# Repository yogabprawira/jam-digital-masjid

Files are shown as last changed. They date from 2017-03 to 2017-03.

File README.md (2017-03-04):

# Jam Digital Masjid

Bahan-bahan yang digunakan:
- Arduino Pro Mini 5V
- Modul RTC DS3231 (sepaket dengan EEPROM AT24C32) 
- MP1584 Buck / Step Down 3A Adjustable Regulator Module
- PCB
- Seven segment
- Resistor
- Kabel
- Power supply (adaptor dengan jack DC 12V) 

Seven segment yang digunakan:
- 4 buah seven segment untuk tampilan jam
- 6 buah seven segment untuk tampilan tanggal/hari
- 4 buah seven segment untuk tampilan jadwal x 6 (Imsyak, Shubuh, Zuhur, Asar, Maghrib, Isya)

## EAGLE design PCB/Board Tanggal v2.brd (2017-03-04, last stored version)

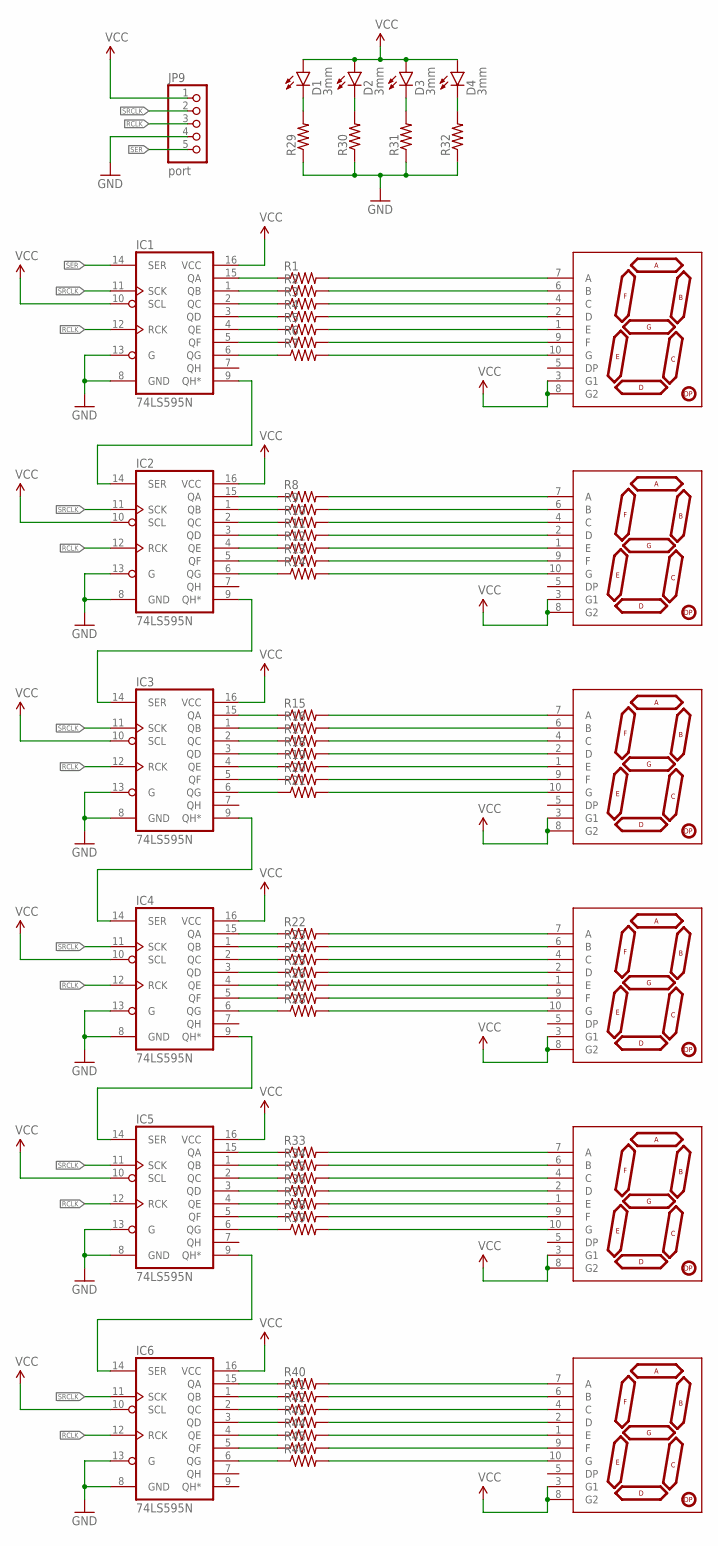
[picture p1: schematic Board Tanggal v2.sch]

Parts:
D1, D2, D3, D4: 3mm; LED3MM
IC1, IC2, IC3, IC4, IC5, IC6: 74LS595N; DIL16
JP9: port; 1X05
R1, R2, R3, R4, R5, R6, R7, R8, R9, R10, R11, R12, R13, R14, R15, R16, R17, R18, R19, R20, R21, R22, R23, R24, R25, R26, R27, R28, R29, R30, R31, R32, R33, R34, R35, R36, R37, R38, R39, R40, R41, R42, R43, R44, R45, R46: RESISTORPTH-1/4W; AXIAL-0.4
U$1, U$2, U$3, U$4, U$5, U$6: 7-SEGMENT-DISPLAY-1"-REDEZ; 7-SEGMENT-1"PTH-EZ

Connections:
A_0: R1.P$2 (2), U$1.7 (A)
A_2: R15.P$2 (2), U$3.7 (A)
A_3: R22.P$2 (2), U$4.7 (A)
A_4: R33.P$2 (2), U$5.7 (A)
A_5: R40.P$2 (2), U$6.7 (A)
B_0: R2.P$2 (2), U$1.6 (B)
B_1: R9.P$2 (2), U$2.6 (B)
B_2: R16.P$2 (2), U$3.6 (B)
B_3: R23.P$2 (2), U$4.6 (B)
B_4: R34.P$2 (2), U$5.6 (B)
B_5: R41.P$2 (2), U$6.6 (B)
C_0: R3.P$2 (2), U$1.4 (C)
C_1: R10.P$2 (2), U$2.4 (C)
C_2: R17.P$2 (2), U$3.4 (C)
C_3: R24.P$2 (2), U$4.4 (C)
C_4: R35.P$2 (2), U$5.4 (C)
C_5: R42.P$2 (2), U$6.4 (C)
D_0: R4.P$2 (2), U$1.2 (D)
D_1: R11.P$2 (2), U$2.2 (D)
D_2: R18.P$2 (2), U$3.2 (D)
D_3: R25.P$2 (2), U$4.2 (D)
D_4: R36.P$2 (2), U$5.2 (D)
D_5: R43.P$2 (2), U$6.2 (D)
E_0: R5.P$2 (2), U$1.1 (E)
E_1: R12.P$2 (2), U$2.1 (E)
E_2: R19.P$2 (2), U$3.1 (E)
E_3: R26.P$2 (2), U$4.1 (E)
E_4: R37.P$2 (2), U$5.1 (E)
E_5: R44.P$2 (2), U$6.1 (E)
F_0: R6.P$2 (2), U$1.9 (F)
F_1: R13.P$2 (2), U$2.9 (F)
F_2: R20.P$2 (2), U$3.9 (F)
F_3: R27.P$2 (2), U$4.9 (F)
F_4: R38.P$2 (2), U$5.9 (F)
F_5: R45.P$2 (2), U$6.9 (F)
GND: IC1.8 (GND), IC1.13 (G), IC2.8 (GND), IC2.13 (G), IC3.8 (GND), IC3.13 (G), IC4.8 (GND), IC4.13 (G), IC5.8 (GND), IC5.13 (G), IC6.8 (GND), IC6.13 (G), JP9.4, R29.P$1 (1), R30.P$1 (1), R31.P$1 (1), R32.P$1 (1)
G_0: R7.P$2 (2), U$1.10 (G)
G_1: R14.P$2 (2), U$2.10 (G)
G_2: R21.P$2 (2), U$3.10 (G)
G_3: R28.P$2 (2), U$4.10 (G)
G_4: R39.P$2 (2), U$5.10 (G)
G_5: R46.P$2 (2), U$6.10 (G)
unnamed: IC1.15 (QA), R1.P$1 (1)
unnamed: IC2.15 (QA), R8.P$1 (1)
unnamed: IC1.1 (QB), R2.P$1 (1)
unnamed: IC1.2 (QC), R3.P$1 (1)
unnamed: IC1.3 (QD), R4.P$1 (1)
unnamed: IC1.4 (QE), R5.P$1 (1)
unnamed: IC1.5 (QF), R6.P$1 (1)
unnamed: IC1.6 (QG), R7.P$1 (1)
unnamed: IC2.1 (QB), R9.P$1 (1)
unnamed: IC2.2 (QC), R10.P$1 (1)
unnamed: IC2.3 (QD), R11.P$1 (1)
unnamed: IC2.4 (QE), R12.P$1 (1)
unnamed: IC2.5 (QF), R13.P$1 (1)
unnamed: IC2.6 (QG), R14.P$1 (1)
unnamed: IC3.15 (QA), R15.P$1 (1)
unnamed: IC3.1 (QB), R16.P$1 (1)
unnamed: IC3.2 (QC), R17.P$1 (1)
unnamed: IC3.3 (QD), R18.P$1 (1)
unnamed: IC3.4 (QE), R19.P$1 (1)
unnamed: IC3.5 (QF), R20.P$1 (1)
unnamed: IC3.6 (QG), R21.P$1 (1)
unnamed: IC4.15 (QA), R22.P$1 (1)
unnamed: IC4.1 (QB), R23.P$1 (1)
unnamed: IC4.2 (QC), R24.P$1 (1)
unnamed: IC4.3 (QD), R25.P$1 (1)
unnamed: IC4.4 (QE), R26.P$1 (1)
unnamed: IC4.5 (QF), R27.P$1 (1)
unnamed: IC4.6 (QG), R28.P$1 (1)
unnamed: IC1.9 (QH*), IC2.14 (SER)
unnamed: IC2.9 (QH*), IC3.14 (SER)
unnamed: IC3.9 (QH*), IC4.14 (SER)
unnamed: D1.K (C), R29.P$2 (2)
unnamed: D2.K (C), R30.P$2 (2)
unnamed: D3.K (C), R31.P$2 (2)
unnamed: D4.K (C), R32.P$2 (2)
unnamed: IC5.15 (QA), R33.P$1 (1)
unnamed: IC5.1 (QB), R34.P$1 (1)
unnamed: IC5.2 (QC), R35.P$1 (1)
unnamed: IC5.3 (QD), R36.P$1 (1)
unnamed: IC5.4 (QE), R37.P$1 (1)
unnamed: IC5.5 (QF), R38.P$1 (1)
unnamed: IC5.6 (QG), R39.P$1 (1)
unnamed: IC4.9 (QH*), IC5.14 (SER)
unnamed: IC6.15 (QA), R40.P$1 (1)
unnamed: IC6.1 (QB), R41.P$1 (1)
unnamed: IC6.2 (QC), R42.P$1 (1)
unnamed: IC6.3 (QD), R43.P$1 (1)
unnamed: IC6.4 (QE), R44.P$1 (1)
unnamed: IC6.5 (QF), R45.P$1 (1)
unnamed: IC6.6 (QG), R46.P$1 (1)
unnamed: IC5.9 (QH*), IC6.14 (SER)
unnamed: R8.P$2 (2), U$2.7 (A)
RCLK: IC1.12 (RCK), IC2.12 (RCK), IC3.12 (RCK), IC4.12 (RCK), IC5.12 (RCK), IC6.12 (RCK), JP9.3
SER: IC1.14 (SER), JP9.5
SRCLK: IC1.11 (SCK), IC2.11 (SCK), IC3.11 (SCK), IC4.11 (SCK), IC5.11 (SCK), IC6.11 (SCK), JP9.2
VCC: D1.A, D2.A, D3.A, D4.A, IC1.10 (SCL), IC1.16 (VCC), IC2.10 (SCL), IC2.16 (VCC), IC3.10 (SCL), IC3.16 (VCC), IC4.10 (SCL), IC4.16 (VCC), IC5.10 (SCL), IC5.16 (VCC), IC6.10 (SCL), IC6.16 (VCC), JP9.1, U$1.3 (G1), U$1.8 (G2), U$2.3 (G1), U$2.8 (G2), U$3.3 (G1), U$3.8 (G2), U$4.3 (G1), U$4.8 (G2), U$5.3 (G1), U$5.8 (G2), U$6.3 (G1), U$6.8 (G2)

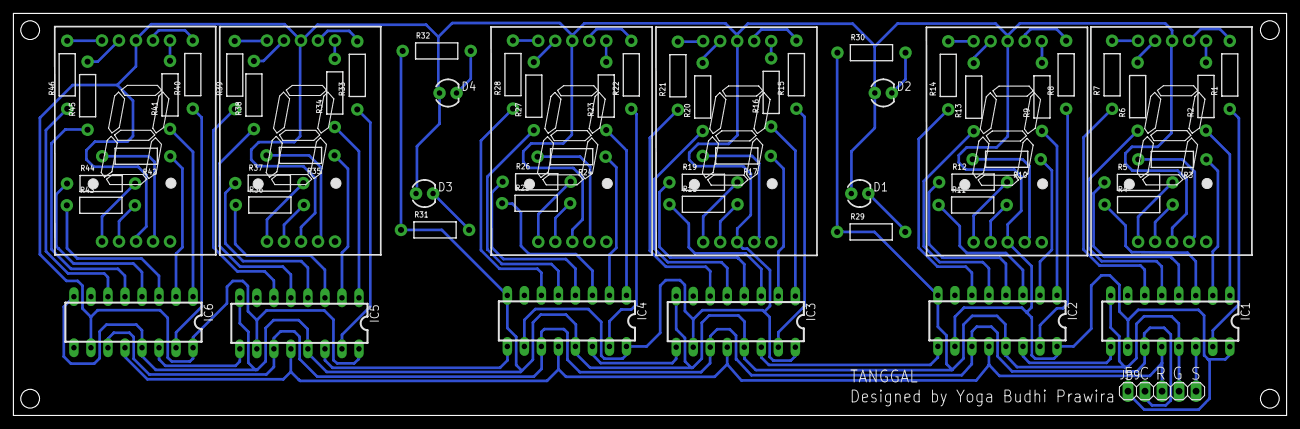
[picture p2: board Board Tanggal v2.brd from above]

Board: 2 copper layers, 190.0 x 60.0 mm, 63 parts (0 on the bottom side), 98 nets.

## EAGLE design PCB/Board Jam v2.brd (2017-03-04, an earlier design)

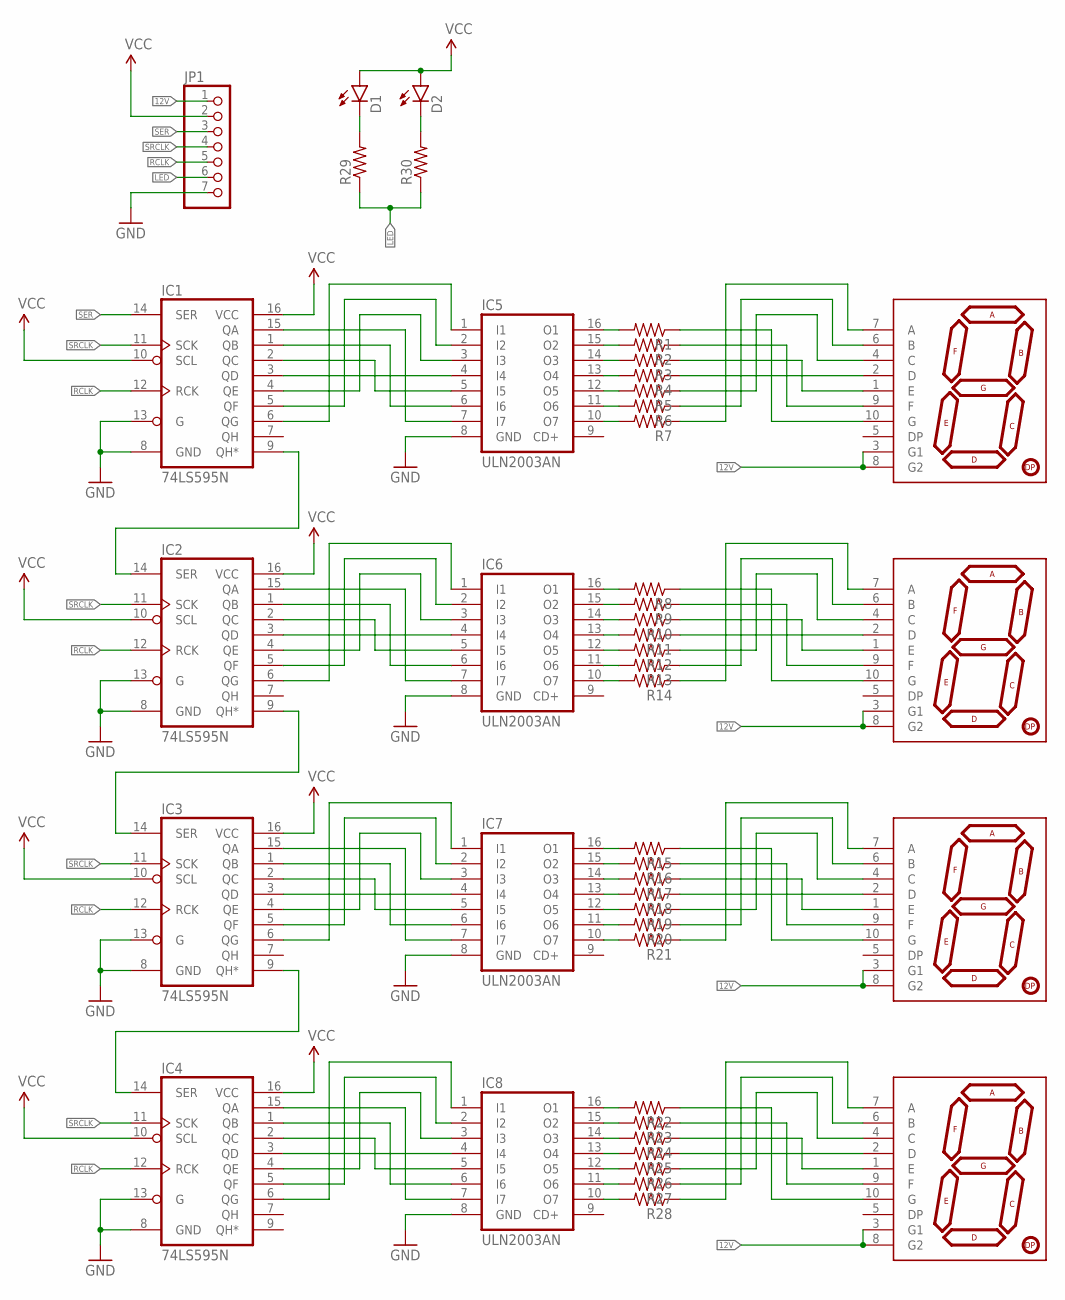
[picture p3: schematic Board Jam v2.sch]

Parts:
D1, D2: LED5MM
IC1, IC2, IC3, IC4: 74LS595N; DIL16
IC5, IC6, IC7, IC8: ULN2003AN; DIL16
JP1: PINHD-1X7; 1X07
R1, R2, R3, R4, R5, R6, R7, R8, R9, R10, R11, R12, R13, R14, R15, R16, R17, R18, R19, R20, R21, R22, R23, R24, R25, R26, R27, R28, R29, R30: RESISTORPTH-1/4W; AXIAL-0.4
U$1, U$2, U$3, U$4: 7-SEGMENT-DISPLAY-1"-RED7-SEGMENT-1.8"PTH; 7-SEGMENT-1"PTH

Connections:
12V: JP1.1, U$1.3 (G1), U$1.8 (G2), U$2.3 (G1), U$2.8 (G2), U$3.3 (G1), U$3.8 (G2), U$4.3 (G1), U$4.8 (G2)
GND: IC1.8 (GND), IC1.13 (G), IC2.8 (GND), IC2.13 (G), IC3.8 (GND), IC3.13 (G), IC4.8 (GND), IC4.13 (G), IC5.8 (GND), IC6.8 (GND), IC7.8 (GND), IC8.8 (GND), JP1.7
LED: JP1.6, R29.P$1 (1), R30.P$1 (1)
unnamed: IC1.15 (QA), IC5.7 (I7)
unnamed: IC2.15 (QA), IC6.7 (I7)
unnamed: IC1.1 (QB), IC5.6 (I6)
unnamed: IC1.2 (QC), IC5.5 (I5)
unnamed: IC1.3 (QD), IC5.4 (I4)
unnamed: IC1.4 (QE), IC5.3 (I3)
unnamed: IC1.5 (QF), IC5.2 (I2)
unnamed: IC1.6 (QG), IC5.1 (I1)
unnamed: IC2.1 (QB), IC6.6 (I6)
unnamed: IC2.2 (QC), IC6.5 (I5)
unnamed: IC2.3 (QD), IC6.4 (I4)
unnamed: IC2.4 (QE), IC6.3 (I3)
unnamed: IC2.5 (QF), IC6.2 (I2)
unnamed: IC2.6 (QG), IC6.1 (I1)
unnamed: IC6.16 (O1), R8.P$2 (2)
unnamed: IC6.15 (O2), R9.P$2 (2)
unnamed: IC6.14 (O3), R10.P$2 (2)
unnamed: IC6.13 (O4), R11.P$2 (2)
unnamed: IC6.12 (O5), R12.P$2 (2)
unnamed: IC6.11 (O6), R13.P$2 (2)
unnamed: IC6.10 (O7), R14.P$2 (2)
unnamed: IC3.15 (QA), IC7.7 (I7)
unnamed: IC3.1 (QB), IC7.6 (I6)
unnamed: IC3.2 (QC), IC7.5 (I5)
unnamed: IC3.3 (QD), IC7.4 (I4)
unnamed: IC3.4 (QE), IC7.3 (I3)
unnamed: IC3.5 (QF), IC7.2 (I2)
unnamed: IC3.6 (QG), IC7.1 (I1)
unnamed: IC1.9 (QH*), IC2.14 (SER)
unnamed: IC2.9 (QH*), IC3.14 (SER)
unnamed: IC3.9 (QH*), IC4.14 (SER)
unnamed: D1.K (C), R29.P$2 (2)
unnamed: D2.K (C), R30.P$2 (2)
unnamed: IC7.16 (O1), R15.P$2 (2)
unnamed: IC5.16 (O1), R1.P$2 (2)
unnamed: IC5.15 (O2), R2.P$2 (2)
unnamed: IC5.14 (O3), R3.P$2 (2)
unnamed: IC5.13 (O4), R4.P$2 (2)
unnamed: IC5.12 (O5), R5.P$2 (2)
unnamed: IC5.11 (O6), R6.P$2 (2)
unnamed: IC5.10 (O7), R7.P$2 (2)
unnamed: IC7.15 (O2), R16.P$2 (2)
unnamed: IC7.14 (O3), R17.P$2 (2)
unnamed: IC7.13 (O4), R18.P$2 (2)
unnamed: IC7.12 (O5), R19.P$2 (2)
unnamed: IC7.11 (O6), R20.P$2 (2)
unnamed: IC7.10 (O7), R21.P$2 (2)
unnamed: IC4.15 (QA), IC8.7 (I7)
unnamed: IC4.1 (QB), IC8.6 (I6)
unnamed: IC4.2 (QC), IC8.5 (I5)
unnamed: IC4.3 (QD), IC8.4 (I4)
unnamed: IC4.4 (QE), IC8.3 (I3)
unnamed: IC4.5 (QF), IC8.2 (I2)
unnamed: IC4.6 (QG), IC8.1 (I1)
unnamed: IC8.16 (O1), R22.P$2 (2)
unnamed: IC8.15 (O2), R23.P$2 (2)
unnamed: IC8.14 (O3), R24.P$2 (2)
unnamed: IC8.13 (O4), R25.P$2 (2)
unnamed: IC8.12 (O5), R26.P$2 (2)
unnamed: IC8.11 (O6), R27.P$2 (2)
unnamed: IC8.10 (O7), R28.P$2 (2)
unnamed: R1.P$1 (1), U$1.10 (G)
unnamed: R2.P$1 (1), U$1.9 (F)
unnamed: R3.P$1 (1), U$1.1 (E)
unnamed: R4.P$1 (1), U$1.2 (D)
unnamed: R5.P$1 (1), U$1.4 (C)
unnamed: R6.P$1 (1), U$1.6 (B)
unnamed: R7.P$1 (1), U$1.7 (A)
unnamed: R8.P$1 (1), U$2.10 (G)
unnamed: R9.P$1 (1), U$2.9 (F)
unnamed: R10.P$1 (1), U$2.1 (E)
unnamed: R11.P$1 (1), U$2.2 (D)
unnamed: R12.P$1 (1), U$2.4 (C)
unnamed: R13.P$1 (1), U$2.6 (B)
unnamed: R14.P$1 (1), U$2.7 (A)
unnamed: R15.P$1 (1), U$3.10 (G)
unnamed: R16.P$1 (1), U$3.9 (F)
unnamed: R17.P$1 (1), U$3.1 (E)
unnamed: R18.P$1 (1), U$3.2 (D)
unnamed: R19.P$1 (1), U$3.4 (C)
unnamed: R20.P$1 (1), U$3.6 (B)
unnamed: R21.P$1 (1), U$3.7 (A)
unnamed: R22.P$1 (1), U$4.10 (G)
unnamed: R23.P$1 (1), U$4.9 (F)
unnamed: R24.P$1 (1), U$4.1 (E)
unnamed: R25.P$1 (1), U$4.2 (D)
unnamed: R26.P$1 (1), U$4.4 (C)
unnamed: R27.P$1 (1), U$4.6 (B)
unnamed: R28.P$1 (1), U$4.7 (A)
RCLK: IC1.12 (RCK), IC2.12 (RCK), IC3.12 (RCK), IC4.12 (RCK), JP1.5
SER: IC1.14 (SER), JP1.3
SRCLK: IC1.11 (SCK), IC2.11 (SCK), IC3.11 (SCK), IC4.11 (SCK), JP1.4
VCC: D1.A, D2.A, IC1.10 (SCL), IC1.16 (VCC), IC2.10 (SCL), IC2.16 (VCC), IC3.10 (SCL), IC3.16 (VCC), IC4.10 (SCL), IC4.16 (VCC), JP1.2

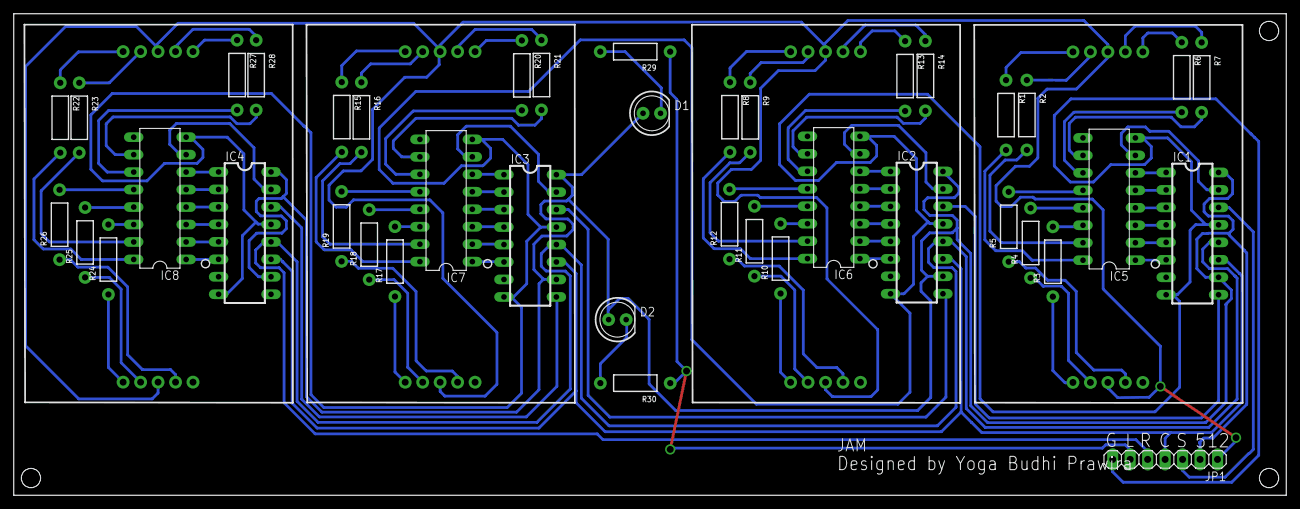
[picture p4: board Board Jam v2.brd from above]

Board: 2 copper layers, 185.0 x 70.0 mm, 45 parts (0 on the bottom side), 96 nets.

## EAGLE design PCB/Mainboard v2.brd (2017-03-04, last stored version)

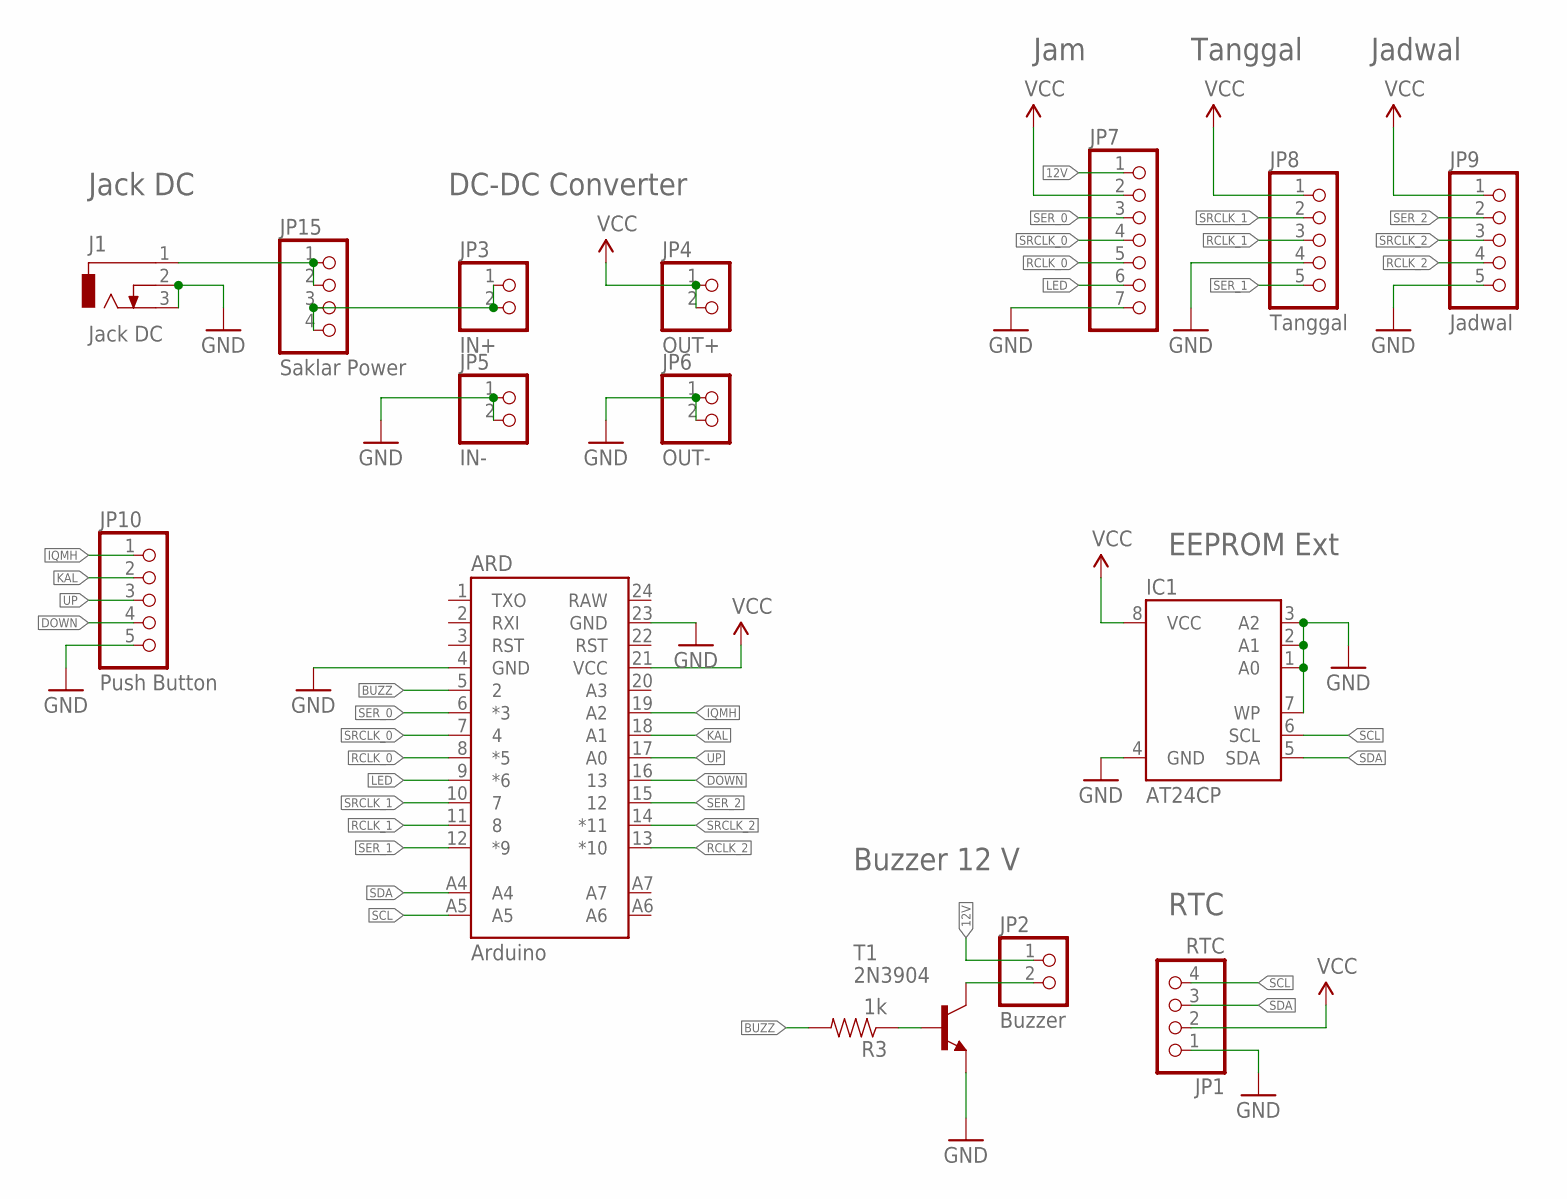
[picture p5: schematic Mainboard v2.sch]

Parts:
ARD: Arduino; ARDUINO_PRO_MINI
IC1: AT24CP; DIL08
J1: Jack DC; DCJ0202
JP1: RTC; 1X04
JP2: Buzzer; 1X02
JP3: IN+; 1X02
JP4: OUT+; 1X02
JP5: IN-; 1X02
JP6: OUT-; 1X02
JP7: PINHD-1X7; 1X07
JP8: Tanggal; 1X05
JP9: Jadwal; 1X05
JP10: Push Button; 1X05
JP15: Saklar Power; 1X04
R3: 1k; AXIAL-0.4
T1: 2N3904; TO92

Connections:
12V: JP2.1, JP3.1, JP3.2, JP7.1, JP15.3, JP15.4
BUZZ: ARD.5 (2), R3.P$2 (2)
DOWN: ARD.16 (13), JP10.4
GND: ARD.4 (GND), ARD.23 (GND), IC1.1 (A0), IC1.2 (A1), IC1.3 (A2), IC1.4 (GND), IC1.7 (WP), J1.2, J1.3, JP1.1, JP5.1, JP5.2, JP6.1, JP6.2, JP7.7, JP8.4, JP9.5, JP10.5, T1.3 (E)
IQMH: ARD.19 (A2), JP10.1
KAL: ARD.18 (A1), JP10.2
LED: ARD.9 (*6), JP7.6
unnamed: R3.P$1 (1), T1.2 (B)
unnamed: J1.1, JP15.1, JP15.2
unnamed: JP2.2, T1.1 (C)
RCLK_0: ARD.8 (*5), JP7.5
RCLK_1: ARD.11 (8), JP8.3
RCLK_2: ARD.13 (*10), JP9.4
SCL: ARD.A5, IC1.6 (SCL), JP1.4
SDA: ARD.A4, IC1.5 (SDA), JP1.3
SER_0: ARD.6 (*3), JP7.3
SER_1: ARD.12 (*9), JP8.5
SER_2: ARD.15 (12), JP9.2
SRCLK_0: ARD.7 (4), JP7.4
SRCLK_1: ARD.10 (7), JP8.2
SRCLK_2: ARD.14 (*11), JP9.3
UP: ARD.17 (A0), JP10.3
VCC: ARD.21 (VCC), IC1.8 (VCC), JP1.2, JP4.1, JP4.2, JP7.2, JP8.1, JP9.1

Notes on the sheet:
RTC
EEPROM Ext
Buzzer 12 V
DC-DC Converter
Jam
Tanggal
Jadwal
Jack DC

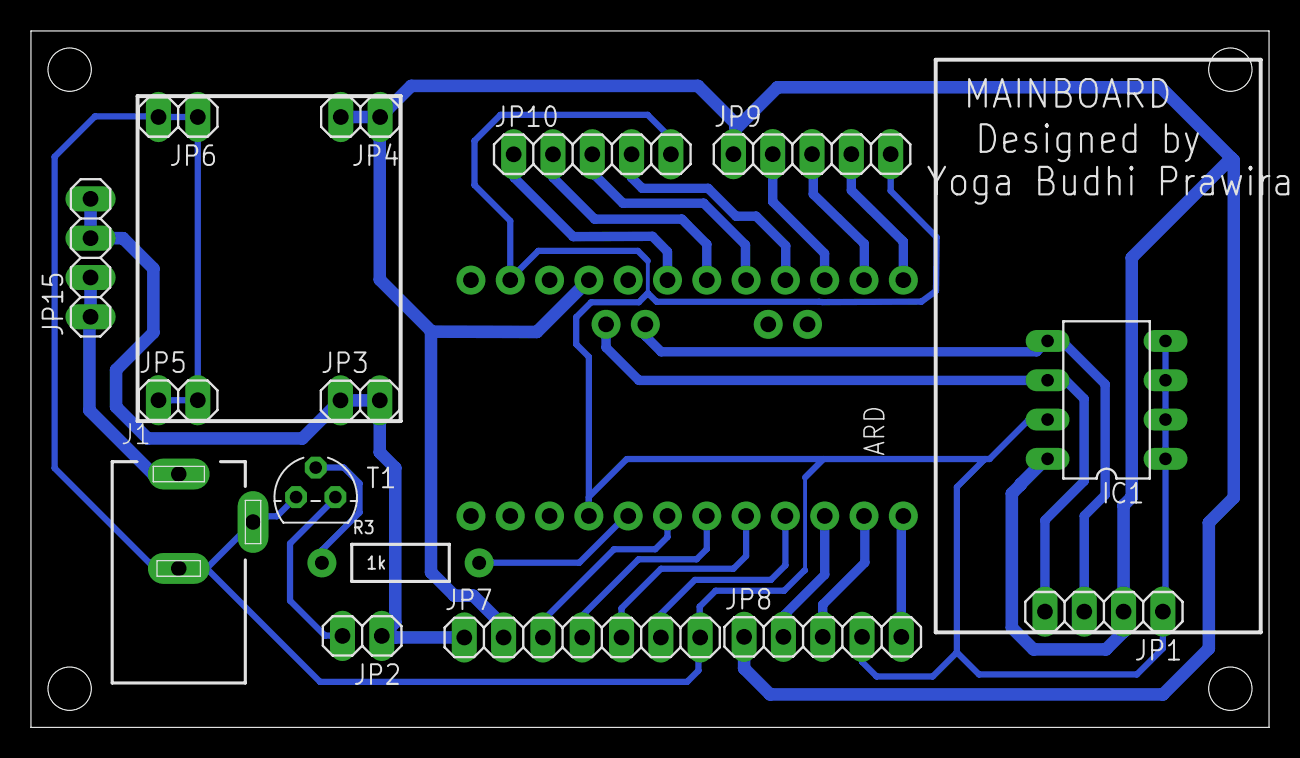
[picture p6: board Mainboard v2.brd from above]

Board: 2 copper layers, 80.0 x 45.0 mm, 16 parts (0 on the bottom side), 23 nets.

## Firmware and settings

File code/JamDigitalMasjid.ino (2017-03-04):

/*
 Name 			:	JamDigitalMasjid.ino
 Created		:	1/26/2016 9:41:18 PM
 Author			:	Yoga Budhi Prawira
 Description	:	Program jam digital masjid sederhana menggunakan arduino pro mini
*/

#include <Wire.h>
#include "AT24C64.h"
#include "Iqomah.h"
#include "Tombol.h"
#include "Kedip.h"
#include "DataJadwalSholat.h"
#include "SevenSegment.h"
#include "JamDigital.h"

/* (SER, RCLK, SRCLK) */
SevenSegment boardJam(3, 5, 4);
SevenSegment boardTanggal(9, 8, 7);
SevenSegment boardJadwal(12, 10, 11);

Kedip buzzer(2);
Kedip ledJam(6);
//Tombol tombolKal(A1);
Tombol tombolIq(A2);
//Tombol tombolGerak(A0);
//Tombol tombolOk(13);

static uint8_t detik, menit, jam, hari, tanggal, bulan, tahun;
static uint8_t menitIqomah, detikIqomah;
//static uint8_t menitKalib, detikKalib;
//static boolean stateInKal = HIGH;
//static boolean stateOutKal = LOW;
//static boolean stateOutKalPrev;
static boolean stateInIq = HIGH;
static boolean stateOutIq = LOW;
static boolean stateOutIqPrev;
//static boolean stateInGer = HIGH;
//static boolean stateOutGer = LOW;
//static boolean stateOutGerPrev = LOW;
//static boolean stateInOk = HIGH;
//static boolean stateOutOk = LOW;
static boolean buzzerNyala;

void setup() {
	//Serial.begin(9600);

	/* Kalibrasi waktu RTC : detik, menit, jam, hari, tanggal, bulan, tahun */
	//jamDigital.kalibrasiRealTime(__DATE__, __TIME__);

	/* Menulis data jadwal sholat ke EEPROM Ext */
	//int i, j;
	/*int bulanTest = DESEMBER;
	for (i = 0; i < 31; i++) {
		for (j = 0; j < 6; j++) {
			dataEepromJadwalSholat.tulisByte(ALAMAT_EEPROM_DS3231, ((bulanTest-1)*186)+(i*6)+j, jadwalSholat.desember[i][j]);
			delay(10);
		}
	}*/
	/* Read EEPROM Test */
	/*for (i = 1; i <= 31; i++) {
		Serial.print(jadwalSholat.jamImsyak(i, bulanTest));
		Serial.print(":");
		Serial.print(jadwalSholat.menitImsyak(i, bulanTest));
		Serial.print(" ");
		Serial.print(jadwalSholat.jamSubuh(i, bulanTest));
		Serial.print(":");
		Serial.print(jadwalSholat.menitSubuh(i, bulanTest));
		Serial.print(" ");
		Serial.print(jadwalSholat.jamDzuhur(i, bulanTest));
		Serial.print(":");
		Serial.print(jadwalSholat.menitDzuhur(i, bulanTest));
		Serial.print(" ");
		Serial.print(jadwalSholat.jamAsar(i, bulanTest));
		Serial.print(":");
		Serial.print(jadwalSholat.menitAsar(i, bulanTest));
		Serial.print(" ");
		Serial.print(jadwalSholat.jamMaghrib(i, bulanTest));
		Serial.print(":");
		Serial.print(jadwalSholat.menitMaghrib(i, bulanTest));
		Serial.print(" ");
		Serial.print(jadwalSholat.jamIsya(i, bulanTest));
		Serial.print(":");
		Serial.println(jadwalSholat.menitIsya(i, bulanTest));
		delay(10);
	}*/

}

void loop() {
	// Baca waktu saat ini dari RTC
	jamDigital.bacaWaktuSekarang(&detik, &menit, &jam, &hari, &tanggal, &bulan, &tahun);

	// Baca state terakhir dan state yang baru
	stateOutIqPrev = stateOutIq;
	tombolIq.bacaState(stateInIq, stateOutIq);
	/*stateOutKalPrev = stateOutKal;
	tombolKal.bacaState(stateInKal, stateOutKal);
	tombolGerak.bacaState(stateInGer, stateOutGer);
	tombolOk.bacaState(stateInOk, stateOutOk);*/

	/*if (stateOutKal == HIGH) {
		if (stateOutKalPrev == LOW) {
			menitKalib = iqomah.getMenitDefault();
			detikKalib = iqomah.getDetikDefault();
		}
		if (stateOutGer != stateOutGerPrev) {
			++detikKalib;
			detikKalib %= 60;
			stateOutGerPrev = stateOutGer;
		}
		boardJam.tampilModeKalibrasi(menitKalib, detikKalib);
	}
	else {*/

	// Kondisi state mode Iqomah
	if (stateOutIq == HIGH) {
		if (stateOutIqPrev == LOW) {
			// Mulai menghitung iqomah
			//iqomah.mulai(iqomah.getMenitDefault(), iqomah.getDetikDefault());
			iqomah.mulai(10, 0);
		}
		// Decrement iqomah per detik
		--iqomah;
		// Mendapatkan nilai iqomah dan state buzzer
		menitIqomah = iqomah.getMenitIq();
		detikIqomah = iqomah.getDetikIq();
		buzzerNyala = iqomah.getStateBuzz();
		// Tampilkan iqomah
		boardJam.tampilJam(menitIqomah, detikIqomah);
		// Ketika mode iqomah, led pada board jam tidak berkedip
		ledJam.setState(HIGH);
	}
	else {
		if (stateOutIqPrev == HIGH) {
			// Matikan buzzer ketika berubah ke mode jam
			buzzerNyala = false;
		}
		// Tampilkan jam
		boardJam.tampilJam(jam, menit);

		// Lampu led pada board jam terus berkedip selama 1 detik hidup 1 detik mati
		ledJam.berkedip(1000, 1000);
	}
	
	/*}*/
	
	// Kondisi apabila buzzer aktif
	if (buzzerNyala) buzzer.berkedip(500, 1000);
	else buzzer.setState(LOW);

	// Tampilkan tanggal
	//boardTanggal.tampilTanggal(tanggal, bulan, tahun);
	boardTanggal.autoSwitchTanggalHari(hari, tanggal, bulan, tahun);
	
	// Tampilkan jadwal imsyak hingga isya
	boardJadwal.tampilJadwal(
		jadwalSholat.jamImsyak(tanggal, bulan), jadwalSholat.menitImsyak(tanggal, bulan),
		jadwalSholat.jamSubuh(tanggal, bulan), jadwalSholat.menitSubuh(tanggal, bulan),
		jadwalSholat.jamDzuhur(tanggal, bulan), jadwalSholat.menitDzuhur(tanggal, bulan),
		jadwalSholat.jamAsar(tanggal, bulan), jadwalSholat.menitAsar(tanggal, bulan),
		jadwalSholat.jamMaghrib(tanggal, bulan), jadwalSholat.menitMaghrib(tanggal, bulan),
		jadwalSholat.jamIsya(tanggal, bulan), jadwalSholat.menitIsya(tanggal, bulan)
		);
	
	// Kondisi ketika masuk waktu sholat : buzzer aktif
	// Buzzer nyala selama 15 detik, kecuali dimatikan dengan menekan tombol iqomah
	if (((jam == jadwalSholat.jamSubuh(tanggal, bulan)) && (menit == jadwalSholat.menitSubuh(tanggal, bulan))) ||
		((jam == jadwalSholat.jamDzuhur(tanggal, bulan)) && (menit == jadwalSholat.menitDzuhur(tanggal, bulan))) ||
		((jam == jadwalSholat.jamAsar(tanggal, bulan)) && (menit == jadwalSholat.menitAsar(tanggal, bulan))) ||
		((jam == jadwalSholat.jamMaghrib(tanggal, bulan)) && (menit == jadwalSholat.menitMaghrib(tanggal, bulan))) ||
		((jam == jadwalSholat.jamIsya(tanggal, bulan)) && (menit == jadwalSholat.menitIsya(tanggal, bulan)))
		)
	{	
		if (detik < 15) buzzerNyala = true;
		else buzzerNyala = false;
	} 
	
	/* Mencocokkan Jam via Serial */
	/*Serial.print(tanggal);
	Serial.print("-");
	Serial.print(bulan);
	Serial.print("-");
	Serial.print(tahun);
	Serial.print("  ");
	Serial.print(hari);
	Serial.print("  ");
	Serial.print(jam);
	Serial.print(":");
	Serial.print(menit);
	Serial.print(":");
	Serial.println(detik);*/
}

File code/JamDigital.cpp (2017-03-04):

/*
 *	Nama File 	:	JamDigital.cpp
 *	Deskripsi	: 	Implementasi dari library JamDigital.h
 */

#include <Wire.h>
#include "JamDigital.h"

#define ALAMAT_DS3231 0x68

uint8_t JamDigital::decToBcd(uint8_t val)
{
	return((val / 10 * 16) + (val % 10));
}

uint8_t JamDigital::bcdToDec(uint8_t val)
{
	return((val / 16 * 10) + (val % 16));
}

JamDigital::JamDigital()
{
	Wire.begin();
}

void JamDigital::
bacaWaktuSekarang(uint8_t *detik, uint8_t *menit, uint8_t *jam, uint8_t *hari, uint8_t *tanggal, uint8_t *bulan, uint8_t *tahun)
{
	Wire.beginTransmission(ALAMAT_DS3231);
	Wire.write(0); // set DS3231 register pointer to 00h
	Wire.endTransmission();
	Wire.requestFrom(ALAMAT_DS3231, 7);
	// request seven uint8_ts of data from DS3231 starting from register 00h
	*detik = bcdToDec(Wire.read() & 0x7f);
	*menit = bcdToDec(Wire.read());
	*jam = bcdToDec(Wire.read() & 0x3f);
	*hari = bcdToDec(Wire.read());
	*tanggal = bcdToDec(Wire.read());
	*bulan = bcdToDec(Wire.read());
	*tahun = bcdToDec(Wire.read());
}

void JamDigital::kalibrasiWaktu(uint8_t detik, uint8_t menit, uint8_t jam, uint8_t hari, uint8_t tanggal, uint8_t bulan, uint8_t tahun)
{
	Wire.beginTransmission(ALAMAT_DS3231);
	Wire.write(0); 
	Wire.write(decToBcd(detik)); 
	Wire.write(decToBcd(menit)); 
	Wire.write(decToBcd(jam)); 
	Wire.write(decToBcd(hari)); // (1=Minggu, 7=Sabtu)
	Wire.write(decToBcd(tanggal)); // (1 to 31)
	Wire.write(decToBcd(bulan)); 
	Wire.write(decToBcd(tahun)); // (0 to 99)
	Wire.endTransmission();
}

uint8_t JamDigital::konversiKe2DigitInt(const char* c) {
	uint8_t puluhan = 0;
	if ('0' <= *c && *c <= '9')
		puluhan = *c - '0';
	return 10 * puluhan + *++c - '0';
}

void JamDigital::kalibrasiRealTime(const char* tanggalSekarang, const char* waktuSekarang) {
	uint8_t detikK, menitK, jamK, hariK, tanggalK, bulanK, tahunK;
	uint8_t offsetK = 13;	// offset dalam satuan detik
	
	switch (tanggalSekarang[0])
	{
		case 'J' :
		{
			if (!memcmp(&tanggalSekarang[1], "a", sizeof(char))) {
				bulanK = 1;
				break;
			} 
			else if(!memcmp(&tanggalSekarang[2], "n", sizeof(char))){
				bulanK = 6;
				break;
			}
			else {
				bulanK = 7;
			}
			break;
		}
		case 'F': bulanK = 2; break;
		case 'A': 
		{
			if (!memcmp(&tanggalSekarang[2], "r", sizeof(char))) {
				bulanK = 4;
			} 
			else {
				bulanK = 8;
			}
			break;
		}
		case 'M':
		{
			if (!memcmp(&tanggalSekarang[2], "r", sizeof(char))) {
				bulanK = 3;
			} 
			else {
				bulanK = 5;
			}
			break;
		}
		case 'S': bulanK = 9; break;
		case 'O': bulanK = 10; break;
		case 'N': bulanK = 11; break;
		case 'D': bulanK = 12; break;
		default: break;
	}
	tahunK = konversiKe2DigitInt(tanggalSekarang + 9);
	tanggalK = konversiKe2DigitInt(tanggalSekarang + 4);
	jamK = konversiKe2DigitInt(waktuSekarang);
	menitK = konversiKe2DigitInt(waktuSekarang + 3);
	detikK = konversiKe2DigitInt(waktuSekarang + 6);
	hariK = konversiTanggalKeHari(tanggalK, bulanK, tahunK);

	detikK += offsetK;
	if (detikK > 59) {
		if (menitK < 59) {
			++menitK;
			detikK %= 60;
		} 
		else {
			menitK = 0;
			if (jamK < 23) {
				++jamK;
			}
			else {
				jamK = 0;
				if (hariK < 7) {
					++hariK;
				} 
				else {
					hariK = 1;
				}
			}
		}
	}

	jamDigital.kalibrasiWaktu(detikK, menitK, jamK, hariK, tanggalK, bulanK, tahunK);
}

uint8_t JamDigital::konversiTanggalKeHari(uint8_t tgl, uint8_t bln, uint8_t thn) {
	if (thn > 2000) thn -= 2000;
	uint16_t totalHari = tgl;
	uint8_t i;
	for (i = 1; i < bln; i++) {
		totalHari += jumlahHariPerBulan[i - 1];
	}
	if ((bln > 2) && (thn % 4 == 0)) {
		++totalHari;
	}
	totalHari += 365 * thn + ((thn + 3) / 4) - 1;
	return (uint8_t)((totalHari + 6) % 7 + 1);
}

JamDigital jamDigital = JamDigital();

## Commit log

2017-03-04 initial files commit
    [Board Jadwal v2.brd, Board Jadwal v2.sch, Board Jam v2.brd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]
2017-03-04 Menghapus buzzer dan led jam library
2017-03-04 Menambah folder .build di .gitignore
2017-03-04 memindahkan PCB ke repository sendiri
    [Board Jadwal v2.brd, Board Jadwal v2.sch, Board Jam v2.brd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]

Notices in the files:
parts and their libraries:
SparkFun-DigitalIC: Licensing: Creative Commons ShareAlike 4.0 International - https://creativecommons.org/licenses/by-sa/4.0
